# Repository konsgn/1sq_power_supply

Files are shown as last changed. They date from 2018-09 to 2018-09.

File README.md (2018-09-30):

# 1 Square Power Supply

A Square inch power supply based on parts from a LM2596 DC-DC buck 
module. Uses an additional Quad-op-amp and STM32F030 to control the 
requlation and display data to the oled screen.

## Big Ticket Components

* MCP6L94 - Quad Op Amp
* SSD1306 - 128*64 oled screen
* LM2596S - Buck Voltage regulator
* STM32F030F4 - Microcontroller
* L78L05 - 5V regulator 
* AP2210N - 3V3 regulator

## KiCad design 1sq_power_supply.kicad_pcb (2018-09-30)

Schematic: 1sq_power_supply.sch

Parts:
C2, C3, C5, C7, C8: C_Small
C4: 4.7u
C6, C9, C10: 1u
C11, C12, C13, C14, C17: 2u2
C15: DNP
C16: 10u
D1: SK54B
D2: M4
D3: D_Small
J1: TC2030-MCP; Homebrew_TC2030-MCP
J2, J3, J4, J5: Conn_01x02
J6: Conn_01x05_Male
L1: 33uH
OLEDM1: SSD1306
R1: 8200
R2: 470
R3: 750
R4, R5, R6, R7, R8, R11: R_Small
R9, R10: 1k5
R12: 10k
R13: 330
R14: .05
U1: L78L05_SOT89; SOT-89-3
U2: LM2596S-ADJ; TO-263-5_TabPin3
U3: STM32F030F4Px; TSSOP-20_4.4x6.5mm_P0.65mm
U4: AP2210N-3.3; SOT-23
U5: MCP6L94

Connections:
3.3v: C3.1, C5.1, C7.1, C12.2, C14.2, J1.1, J6.1, OLEDM1.6, OLEDM1.9, OLEDM1.11, U3.5, U3.16, U4.2 (VO)
5v: C4.1, C6.1, U1.1 (OUT), U4.3 (VI), U5.4 (V+)
/A_Limit: R10.2, U3.13
/A_Sense: C15.1, R11.2, U3.10, U5.1, U5.5 (+)
/Aset: C10.1, R10.1, U5.6 (-)
/BTN: J6.2, U3.8
/FB: D3.1, R1.2, R2.2, R3.1, U2.4 (FB)
/GNDout: J5.1, J5.2, R14.1, U5.3 (+)
/LCDRST: OLEDM1.14, U3.3
/PotSense: J6.4, U3.11
/RX: J6.3, U3.9
/SCL: OLEDM1.18, U3.17
/SDA: OLEDM1.19, OLEDM1.20, U3.18
/SWC: J1.4, U3.20
/SWD: J1.2, U3.19
/V_Target: R9.2, U3.12
/Vctrl: R3.2, U5.8, U5.9 (-)
/Vi_Sense: R4.1, R5.2, U3.7
/Vo_Sense: R6.1, R7.2, U3.6
/Vset: C9.1, R9.1, U5.10 (+)
/~RST: J1.3, U3.4
GND: C2.2, C3.2, C4.2, C5.2, C6.2, C7.2, C8.2, C9.2, C10.2, C12.1, C14.1, C16.2, C17.2, D1.2, D2.2, J1.5, J3.1, J3.2, J6.5, OLEDM1.1, OLEDM1.8, OLEDM1.10, OLEDM1.12, OLEDM1.13, OLEDM1.15, OLEDM1.16, OLEDM1.17, OLEDM1.21, OLEDM1.22, OLEDM1.23, OLEDM1.24, OLEDM1.25, OLEDM1.29, OLEDM1.30, R2.1, R5.1, R7.1, R8.2, R12.1, R13.2, R14.2, U1.2 (GND), U2.3 (GND), U3.15, U4.1 (GND), U5.11 (V-)
unnamed: C11.1, OLEDM1.3
unnamed: C11.2, OLEDM1.2
unnamed: C13.1, OLEDM1.5
unnamed: C13.2, OLEDM1.4
unnamed: C15.2, R8.1, R11.1, U5.2 (-)
unnamed: C16.1, OLEDM1.28
unnamed: C17.1, OLEDM1.27
unnamed: D1.1, L1.2, U2.2 (OUT)
unnamed: D3.2, U5.7
unnamed: OLEDM1.26, R13.1
unnamed: R12.2, U3.1
Vin: C2.1, D2.1, J2.1, J2.2, R4.2, U1.3 (IN), U2.1 (VIN), U2.5 (~ON~/OFF)
Vout: C8.1, J4.1, J4.2, L1.1, R1.1, R6.2

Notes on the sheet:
Aboost
Acomp
TIM3_CH1
TIM3_CH2
VBuffer

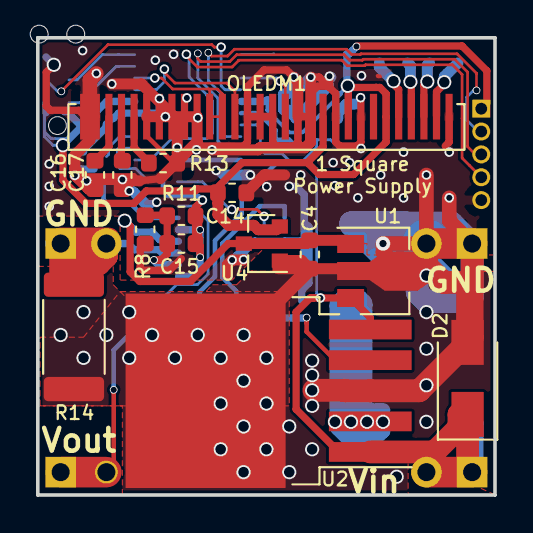
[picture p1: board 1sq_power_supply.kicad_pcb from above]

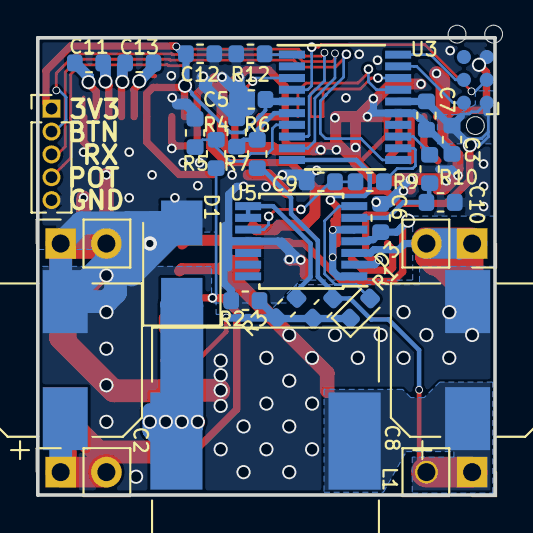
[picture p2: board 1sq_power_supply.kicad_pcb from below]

Board: 2 copper layers, 25.4 x 25.4 mm, 46 parts (32 on the bottom side), 35 nets.

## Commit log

2018-09-30 First Commit -v0.1
    [1sqPowa_DacEval.ods, 1sq_power_supply.kicad_pcb, 1sq_power_supply.sch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]
2018-10-03 added footprints
    [1sq_power_supply.sch]
2019-02-22 2-22-19 update
    [1sq_power_supply.sch]
